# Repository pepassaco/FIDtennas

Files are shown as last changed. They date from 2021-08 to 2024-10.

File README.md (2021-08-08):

# FIDtennas
Open-source RF hardware repository. Visit [FIDtennas](https://www.fidtennas.ga) for additional info about this project.

*Designs by Pablo EA1FID*

## Structure of the repo

This repo follows the next structure:

    .FIDtennas
    ├── README.md
    |
    ├── 3D parts
    |
    ├── Antennae
    │   ├── Satellite
    │   │   ├── Aiga
    │   │   │   ├── images
    │   │   │   ├── results
    │   │   │   ├── model
    │   │   │   └── README.md
    │   │   ├── ...
    │   |
    │   ├── 6m
    │   │   └── ...
    │   |
    │   ├── 4m
    │   │   └── ...  
    |   ├── ...
    |
    └── Other   

Inside the *images* forder there will be images either of the 3D model of the antenna, its plans or the final build. 

The folder *results* contains the .s1p or .csv files corresponding to real-life antenna measurements.

Inside *model* there is the .cst files of the antenna model used during the design phase in CST Studio.

Finally, the README file of every antenna describes its main characteristicas and specifications and provides the necessary plans or building guides if needed.

## License

Al this designs are under a GNU GPL v3 license. You may freely use them to build your own hardware, modify it according to your needs or improve it, always mentioning either FIDtennas or EA1FID as the designer of the original version.

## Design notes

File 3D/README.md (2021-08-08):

# 3D printable supports

### Naming

    XY-ZZZ-WWW_vU.stl

**X:** detachable/fixed
 
 - D: detachable elements
 - F: fixed elements (bolt thought hole)

**Y:** shape of boom cross-section

 - C: circlar section
 - S: square section

**ZZZ:** diameter of boom (mm)

**WWW:** diameter of element (mm)

**U:** version

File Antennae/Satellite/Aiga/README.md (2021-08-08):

# Aiga

### Specifications

All of the specifications of the Aiga antenna can be found in [our website](https://www.fidtenas.ga/blog/2021-08-08-aiga/)

## Plans

### VHF / 2m

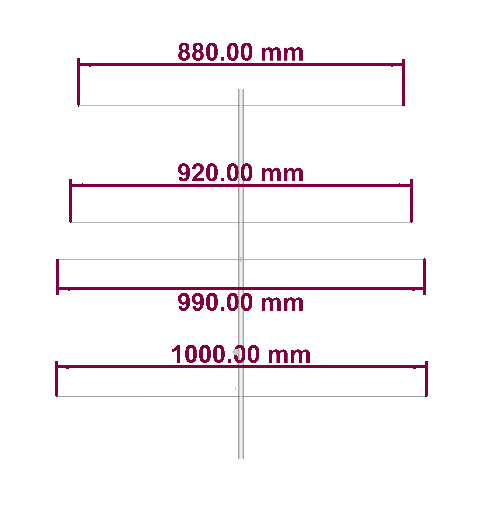
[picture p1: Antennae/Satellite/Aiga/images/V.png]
VHF


#### Lengths

| Element  | Length (mm) |
|:---:|:---:|
|  Refletor  | 1000 |
| Dipole | 990 |
| Director 1 | 920 |
| Director 2 | 880 |

#### Spacing

| Space | Distance (mm) |
|:---:|:---:|
| Refletor - Dipole | 370 |
| Dipole - Director 1 | 100 |
| Director 1 - Director 2 | 315 |

### UHF / 70cm 

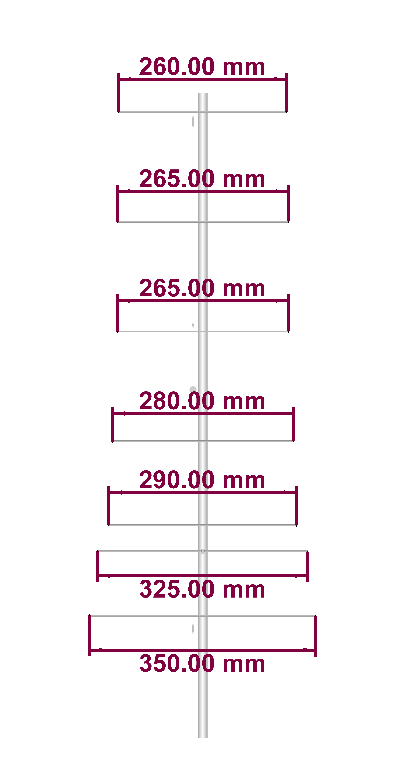
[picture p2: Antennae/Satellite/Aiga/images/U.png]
UHF


#### Lengths

| Element  | Length (mm) |
|:---:|:---:|
|  Refletor  | 350 |
| Dipole | 325 |
| Director 1 | 290 |
| Director 2 | 280 |
| Director 3 | 265 |
| Director 4 | 265 |
| Director 5 | 260 |

#### Spacing

| Space | Distance (mm) |
|:---:|:---:|
| Refletor - Dipole | 100 |
| Dipole - Director 1 | 40 |
| Director 1 - Director 2 | 130 |
| Director 2 - Director 3 | 170 |
| Director 3 - Director 4 | 170 |
| Director 4 - Director 5 | 170 |

**Important remarks:**

- The length of the boom is not important provided that it is long enought to support all elements (820mm + what you consider the most confortable for grabbing the antenna).
- The last element of the antenna must be the Director 5 for the UHF band. It must be placed at the most top of the boom
- The Director 2 for the VHF band must be placed exactly 10mm under the Director 5 for the UHF band. This is easily done if you print out 3D supports. Since their width is just 10mm, this is achieved by placing them contiguously.
- Once you have placed these two elements, start measuring the distances between the rest of them in order to build the antenna.
- It is highly recommended drawing some marks on the boom corresponding to the exact **position** and **orientation** of each element. In this way, it is possible to assemble the antenna pretty fast (in under a minute!).
- For extra detail about this antenna and a building guide, visit [our website](https://www.fidtenas.ga/blog/2021-08-08-aiga/)

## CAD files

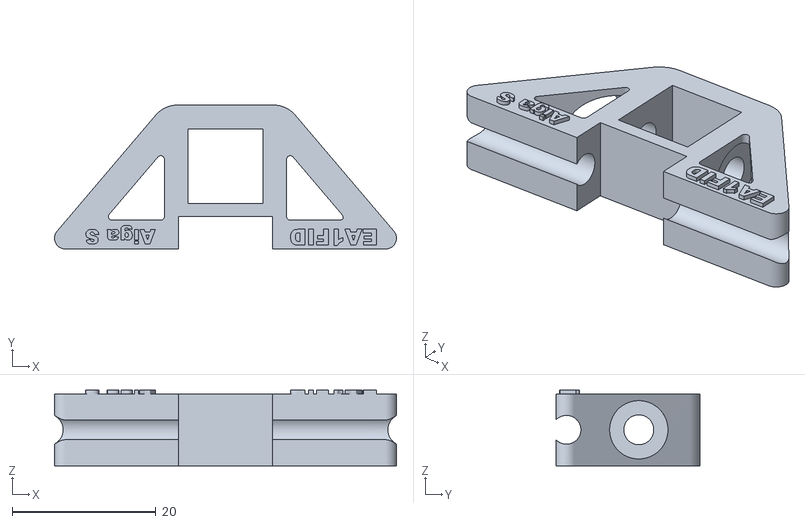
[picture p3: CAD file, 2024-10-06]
3D/DS-10-4_v3dip.stl
47.5 x 20.0 x 10.5

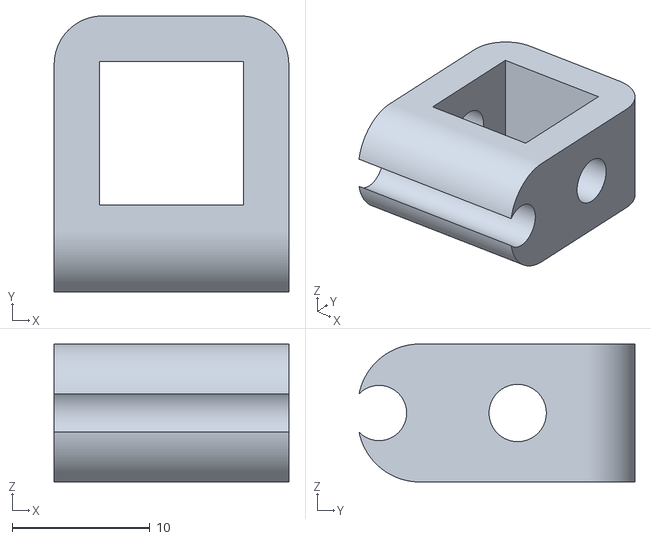
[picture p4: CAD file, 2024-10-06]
3D/DS-10-4_v3elem.stl
17.0 x 20.0 x 10.0

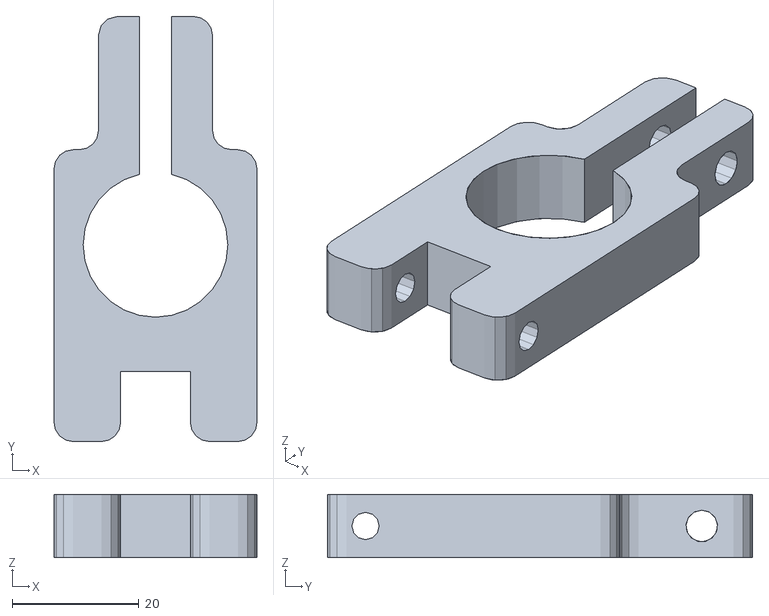
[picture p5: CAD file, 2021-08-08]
3D/DC-22-4_v0.stl
32.0 x 67.0 x 10.0

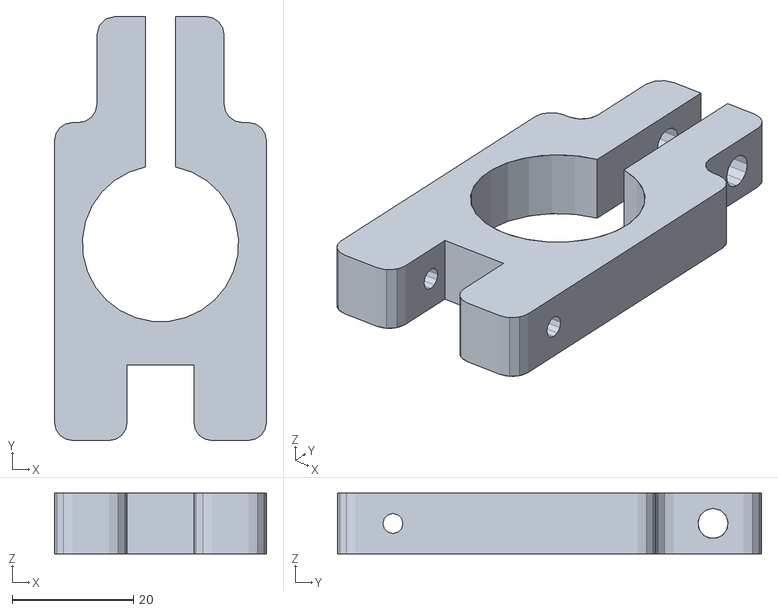
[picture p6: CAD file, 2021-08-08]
3D/DC-25-3_v0.stl
35.0 x 70.0 x 10.0

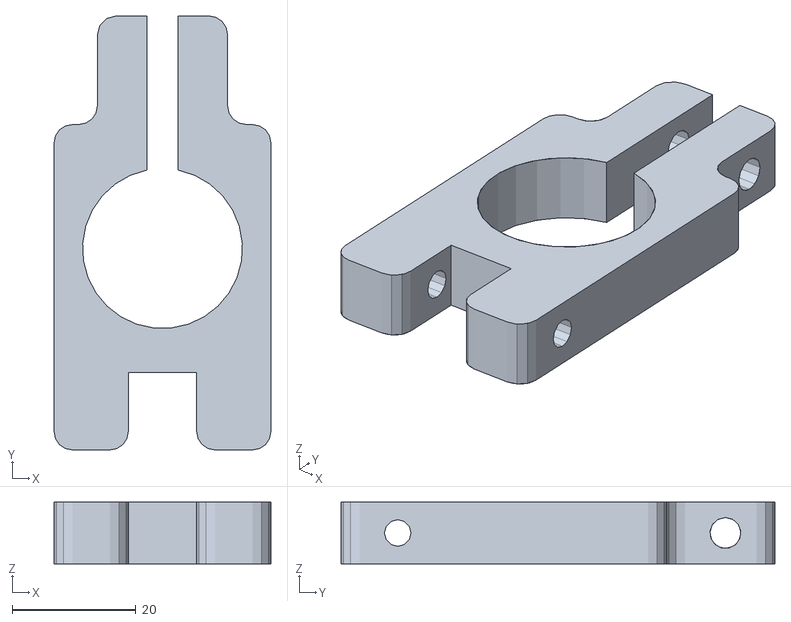
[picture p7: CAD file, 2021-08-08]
3D/DC-25-4_v0.stl
35.0 x 70.0 x 10.0

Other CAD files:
3D/DC-22-3_v0.stl
